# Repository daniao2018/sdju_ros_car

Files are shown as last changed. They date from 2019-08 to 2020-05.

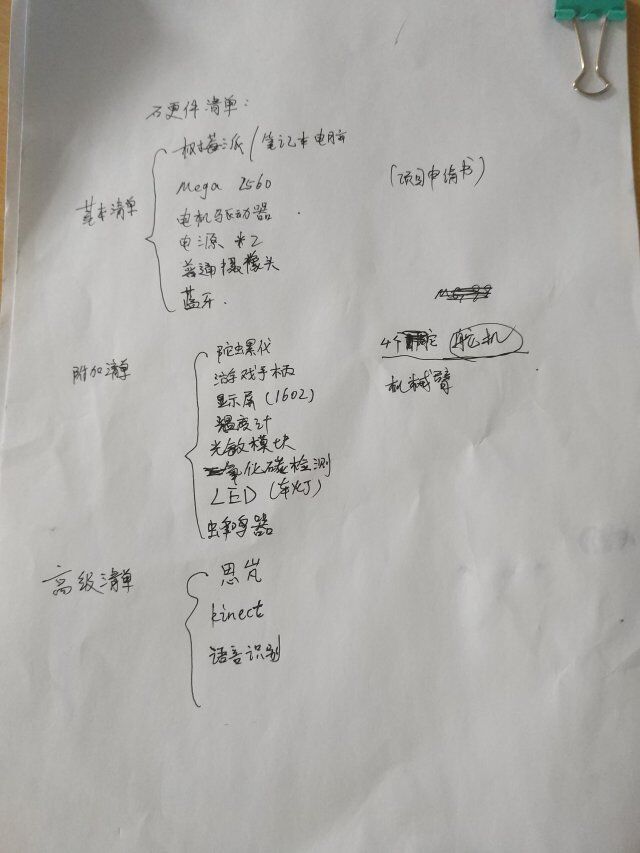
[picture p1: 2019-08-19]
开发文档/项目总体/硬件清单.jpg

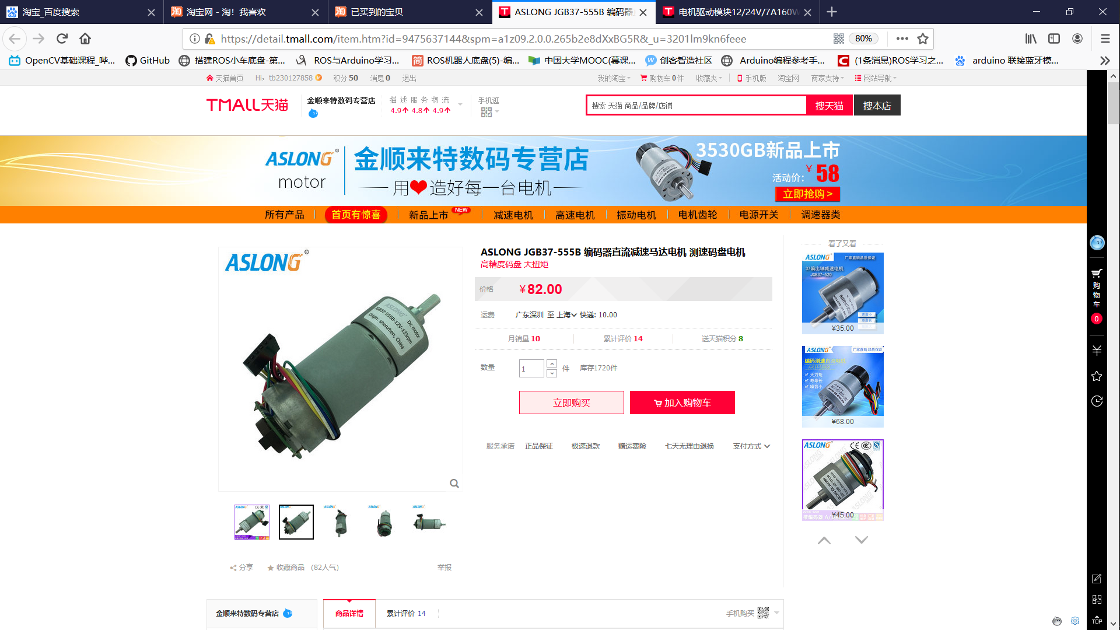
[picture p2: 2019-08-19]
电路部分_F1/电路部分/模块补充图/编码电机.png

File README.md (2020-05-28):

## ROS_Car- 项目介绍

## 项目简介
本项目是博主申请的上海市科创的一部分，题材是基于ROS设计出一款智能配送车，预计经费9000，时间一年。预期成果专利一项。19年3月开题答辩通过，到现在进展了5个月。开展这个项目，是因为博主大一暑假在某家公司实习从事ROS的开发，方向视觉，觉得挺好玩的~~~然后项目申请下来，n多坑，有喜有泪~~~,泪的多。

## 机械结构
项目的机械结构已经完成，小组自主设计了一辆ros小车的机械结构，完成了sw的建模，以及自己加工的过程，太苦了，整个据出来的机械结构。后期可能会请工厂代加工，由于这部分是专利的重点，博主本着保命原则，该部分不开源！！！！
## 电路部分
项目的电路部分已经完成，用fritzing画完了电路图，不会用AD，自己照着仿真图，买现件焊接了小车的电源部分。重点是12v，5v的取电，以及相关按钮的嵌入。在该部分小组还用fritzing画出了项目的连线示意图以及注意事项。
## 代码部 
项目的代码部分，中间层，以及底层都已经完成，可以用opencv，键盘控制小车的运动，后期还有很大的改善空间。主要是一些高级功能模块的迁入。

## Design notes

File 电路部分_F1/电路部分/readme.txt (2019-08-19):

  该部分是小车的电路部分，包括电源模块，小车底盘模块，外置模块以及相关信息的补充。
连线时需考虑代码部分的说明，本部分的某些图的连线方式与代码可能不完全一致，
应以代码部分为主。

配图说明
底盘原理图:
     该部分主要包括电机，电机驱动器，arduino mega 2560 的连线以及取电。：
外置模块电路图：
     该部分主要包括树莓派，arduino mega 2560,蓝牙模块，led,usb摄像头，按钮的取电以及
连接，具体功能模块可以再此模块中拓展。
电源模块：
     该部分主要是通过2块12v的电池给系统提供电力，分别是12v,5v,5v3A稳流，具体分配见图

总体电子元器件（可拓展）
     树莓派
     arduino mega 2560
     电池 12v *2
     直流无刷电机 *2
     电机驱动器
     usb 摄像头
     电源转化器（见附图） *2
     hc-05蓝牙模块
     按钮 *3
     led *n

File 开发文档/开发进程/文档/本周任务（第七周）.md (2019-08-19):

# 本周任务

**电机的调试以及小车模型的建立校正。
项目负责人;高俊，龙宏生。**
## 电机型号：
直流无刷电机，三相五霍尔。100w6A电流（注意安全）2*118元

[电机型号](https://item.taobao.com/item.htm?spm=a230r.1.14.30.3c8f62d0JOuXSm&id=573268079845&ns=1&abbucket=11#detail)
## 电机驱动器：
不提供原理图代码，只提供接线方式，模拟/pwm/电位调速 注意卖家提供的淘宝页信息（后期可更换2*280）       2*46 元

[电机驱动器](https://item.taobao.com/item.htm?spm=a230r.1.14.154.241e3a82ss7VLk&id=534792853206&ns=1&abbucket=11#detail)
## 单片机 stm32控制：
注意stm32的原理图，以及引脚问题。注意差速（pwm）提供转向，不知驱动器里是否有急停，正反转模块？注意系统的学习一下stm32，特别是寄存器的使用，后期的发送数据。 250元
注：不熟悉pwm可来我寝室那块arduino板来pwm调速
[stm32链接](https://s.taobao.com/search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)
## 模型
小车制做完后，可以sw转urdf，在ros中制作好模型。
## 注意事项：
1.	开发流程请注意规范，注意注释的编写
2.	注意培养好阅读博客的好习惯，每一篇博客请精读
3.	注意自己项目笔记的书写
4.	注意项目的进度

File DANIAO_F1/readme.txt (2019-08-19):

/**********总体框架*******************/
/
/test包，小车的中间层，与arduino进行通信，具体见包里面的readme

roslaunch test arduino.launch

//两种控制方式，机理都是发送x,y线速度，z的角速
--------opencv

//先运行usb_cam,启动摄像头

roslaunch usb_cam usb_cam-test.launch

//启动opencv的相关配置

roslaunch opencvfinally 

---------键盘

teleop_twist_keyboard teleop_twist_keyboard.py

调试用的小工具************/

-------检查串口
ls /dev/tty*

------单独编译某个包
catkin_make -DCATKIN_WHITELIST_PACKAGES="test"

-------话题相关
rqt_graph //检查话题之间的关系
rostopic list 
//显示所有话题
rostopic info XXXX //显示单个话题之间订阅以及接收

---------速度相关
rostopic pub /cmd_vel geometry_msgsros/Twist -r 1 -- '[2.0, 0.0, 0.0]' '[0.0, 0.0, 1.8]'

//发布速度
rostopic echo /odom  ？

rosrun rqt_plot rqt_plot
图形化显示？
/odom/pose/pose/orientation

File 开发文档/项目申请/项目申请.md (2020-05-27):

# 项目申请
## 简介

该部分是以前博主为参加项目答辩而攥写的ppt的一部分，主要包括项目人员，研究意义，ros简介，创新点，机械结构，控制方案，现有技术积累等几部部分。现在提取其中的一部分作说明。
## 项目人员

选人组队，好难啊！毕竟是真的要干活的啊，，，当时不懂啊，选了个机制画图，完全正确决定，老哥画图太强了。选了两个本班的，也还可以，毕竟关系亲近。再莫名其妙的塞了两个大一的，带带他们也还说的过去。然后现在好多事情都要我亲自搞，有点累！！！想要考研啊，难受。
## 创新点

当时胡乱写的，答辩的时候被老师怼的不要不要的，主要是机械结构的创新上，你们这个机械结构有什么创新啊？和外面的有什么不同啊？博主当时脑袋一片空白，机械结构不归我管啊，虽然机械结构的加工，组装方式是我提出的，但是当时是为了更好的设计出来这个东西，哪里想过这种事情，毕竟当时草略的sw以经建好了。答辩的结果是博主被老师赶下去了，下一个。难受，难受。
## ROS 简介
略，老师根本没怎么看。
## 控制方案
准备好好讲的时候，被老师赶下去了，太尴尬了。现在想想，控制部分没有什么大的问题，主要是蓝牙模块这方面，是用树莓派内置的，还是外接，或者连到arduino上？？还是很模糊的，而且作为配送车，如何人机互动，用蓝牙开锁没有说清楚，还是有的问题的。
## 总结
该部分是项目的申请部分，当时忙碌了，好久好久，脑段痛，现在想想还是可以的啦。

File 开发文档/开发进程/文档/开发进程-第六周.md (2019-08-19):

# 开发进程-第六周
## 开发规范：
~~请不要讲本项目相关资料外泄~~，谢谢！在Linux平台开发，使用语言，推荐python，也可以用c++。请注意python的缩进格式！编译器使用Linux自带的gredit，可以使用roboware来解决python的缩进问题。写代码时，请注意添加注释，多使用函数类型，少使用全局变量，注意Ros的编程规则，在软件包的外面，请使用空白文档写下，该软件包的运行代码，以及简单注释。
## 技术方案（老版）
该技术方案制定于3月初的样子，后期变化挺大的，在下位机的层次方面，小组使用了arduino mega 2560 代替了stm32。具体原因是某组员居然烧掉了块stm32，小组决定换个容易点的控制方案。总体的时间流程倒是没有什么大的变化。当然这只是大概的技术方案。
技术方案
### 难点：
   请注意专利的撰写时间，请与暑假完成初稿。
   请小车设计的人，设计小车时，考虑他的~~实用新型专利的申请~~（发明）
   请负责控制电机的人学习一下~~stm32的控制方式~~
   请负责整体模块的人保证项目能顺利完成，以及时间进度的控制

### 详细计划：
1.	滋定于每周的星期六晚上开讨论会，如有需要请大家带上笔记本，一起讨论一下本周遇到的问题。
2.	计划借一个实验室用来存放东西，以及学习。
3.	请各模块的负责人把握一下开发进度，遇到问题请及时解决。
项目人员
4.	专利攥写人员，及财务管理：龙宏生，孟纪元
5.	请注意各位培养自己发现问题，解决问题的能力。注意社区，qq群资料的获取。也请各位沉下心来踏实做事。

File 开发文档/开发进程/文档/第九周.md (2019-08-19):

# 第九周
<font color =Coral>测试了arduino对实时ros的通信，主要是通过serial包来进行通讯。</font>
第九周
## 暴露的问题：
1.	arduino的存储能力有限，在执行端不可能写入太多代码，可能也就是数据的写入与pwm调速的功能。
2.	一块arduino板只能写一个节点，完成几个特定的任务？
第九周（二）
3.小车的运动模型还没有建立好，主要是两轮驱动差分底盘的相关问题。即小车转动的角度与两个轮子的数学关系式的问题。
第九周（三）

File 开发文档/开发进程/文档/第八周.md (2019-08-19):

# 本周计划
<font color=red size=3 >以后的讨论，将更多的由各个模块的负责人讨论项目相关进展！注意预期的时间表! </font>
第八周
## Arduino调试中遇到的问题：
1.	电机驱动器的正反转机理没有搞懂。
2.	调试过程中电机没有到达额定功率，24*1.9<100。可能是驱动器（更大）或者电源的保护。
3.	相应的字符串输出没有调试清楚，会出现乱码与报错的问题。
## 具体事宜
1.	请负责底盘控制的人在调完pwm后，注意解决以上问题。
2.	请负责车体的机械结构的人在购买零件时，注意性价比，在上海市那边的钱没有批下来之前，小组只有三百左右的钱支持你的机械结构的设计。
3.	请负责专利撰写的人注意相应知识的学习，也请负责机械结构的人多和他合作一下。
4.	<font color=red size=3 >请各个模块的负责人/组员注意整理项目进展中，遇到的问题，并整理成相应笔记。模块的负责人可以尝试像我这样制作相应模块的本周文档，用来整理项目进展。以后的讨论，更多的是各个模块负责人的讨论以及交流。
 </font>
## 人员的整体框架
人员的整体框架
人员的整体框架（二）
## 项目的预期时间进展表：
•	4月基本了解ROS系统，Linux开发。
•	5月20号之前组装好小车，stm32可以熟练的控制小车的运动。
•	6-7月调试小车的程序，购买其他器件，考虑考试期，希望大家考个好成绩。
•	7-9月，留校调试系统程序，完成一些项目之外的工作，如机器语音，人脸识别，slam自主导航
<font color=red size=3 >•	请负责专利的人在九月之前完成专利申请书的样式，撰写相关专利。 </font>
•	9月，确保小车的功能达到之前的技术积累，并有适当的其他技术积累。
•	10-12月二次开发，添加一些好玩，实际的功能，解决具体实际问题（好参加比赛）。
<font color =red size=3 >•1月以后，预留时间请勿占用。</font>
## 项目开发规范：
<font color =red size=3 >参考以前文档</font>

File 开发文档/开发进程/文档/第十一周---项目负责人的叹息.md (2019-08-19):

# 第十一周---项目负责人的叹息
项目已经开展了一个多月，可以说本学期可以用来完成项目的时间已经不多了，前面的几周一直在讲，相关规范以及如何解决具体问题，也不知道你们听进去了多少，<font color=red size=4>后面的工作应该更多的由相关的项目负责人完成。</font>
**客观的来说，本次项目的开发还是挺有难度的**，主要是任务多（车体的机械结构，底盘的控制，ros编程及相关算法），组员相关知识薄弱（能编程以及会单片机的人少）。<font color=red size=4>有些组员承担了过多的压力，而有些组员则明显的不知道自己要干什么。</font>当然，这也和我的分工以及人员的组配有关。<font color=red size=4>很明显，有些任务太难了，需要的时间有点长，这个时候需要waiting & help。</font>有些组员由于个人原因以及其他原因是得寻找一些适合他的活干，这也是一个大问题。
作为项目负责人，如何分配任务，以及考虑人员的能力还是有点挑战性的，你不可能每一件事情，都亲自去做。也不可能将一些明显不适合组员的任务分配下去。
**总的来说，是希望每一个组员通过这个项目学到点什么，有自己的一技之长的。当然，站在组长的角度上来看，我首先得保证项目得顺利完成以及相应功能的实现。站在个人的角度来看，你是不希望由于这个项目而破坏同学之间的友谊的。**

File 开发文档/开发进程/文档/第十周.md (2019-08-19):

# 项目陷入了瓶颈期
### 具体体现在如下方面：
**1.	大概有300块钱的东西被烧了（一个stm32和一个驱动板）
2.	控制思路不清晰，小车定位有点问题。**
### 控制思路：
第十周

<font color=red size =5>大意如下：</font>
第十周（二）
### 小车定位：
**以完成申请书上的东西为主，可以负重一点点，但重点不是落在负重上。而是小车的机械结构与控制上。**
第十周（三）
## 一些问题：
<font color=red size=3>a.电机的选型出了问题，100w/2500转，导致转矩为0.4n*m，不能承重？解决方法？</font>
1.增加减速机构，以增大转矩。
2.换电机，底层机械设计重新改进
  个人偏向第二种解决方法：第一种方案可以保留，如果有人想继续做下去的话，思路是增加减速结构，选一个好一点的驱动器（2个500以上？），能读出转速发送给单片机的那种，然后整合到小车上。
<font color=red size=3>b.时间，时间，时间，这个项目很有挑战性，花的时间有点多，需要克服一下。而且马上就期末了，我不可能揽下所有事情，所以会有分工。</font>
c.	干活毅力很重要，现在出现的一些问题都是小问题，不要乱了阵脚。
#### d.	小车的一些性能指标:
1.	最大线速度1m/s 
2.	转矩6n*m以上，可能还要计算一下
3.	预期称重30kg

**e	购买东西：预算3000左右，等上海市那边的钱批下来，先看。**
电池：500  	
树莓派：300-400 // 32g内存，3b（3b+）
直流无刷减速电机*2    300  //AB相编码器
Stm32：200
机械结构 500 
Arduino：200-250 //uno mege2560
Kinetic  300（不知道有发票吗）
Imu 200
语言识别模块 200
硬盘*2  100

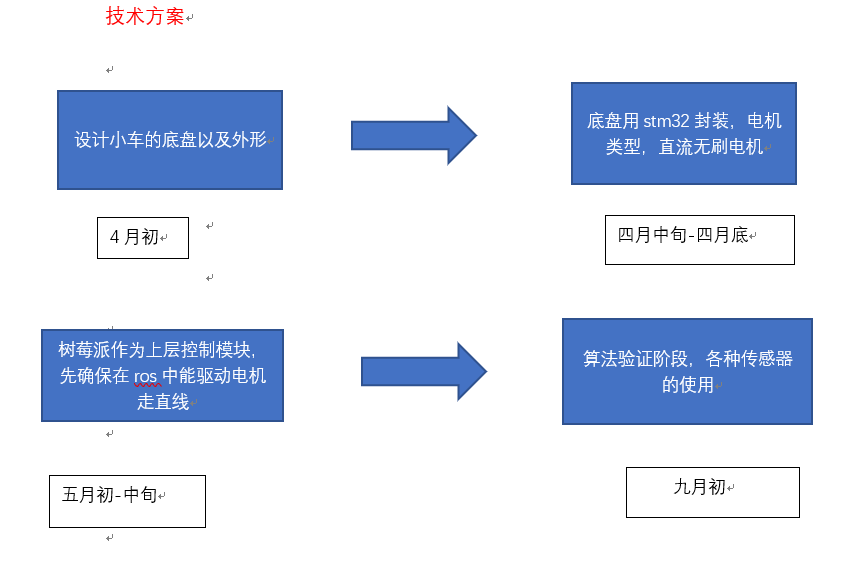
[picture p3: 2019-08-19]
开发文档/开发进程/图片/技术方案.png

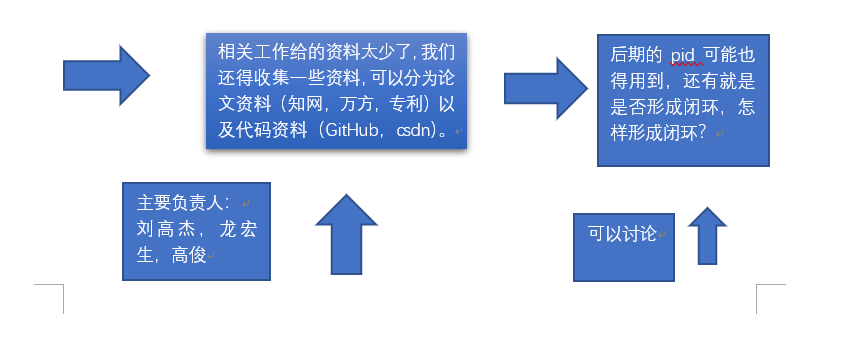
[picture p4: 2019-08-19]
开发文档/开发进程/图片/第九周（三）.png

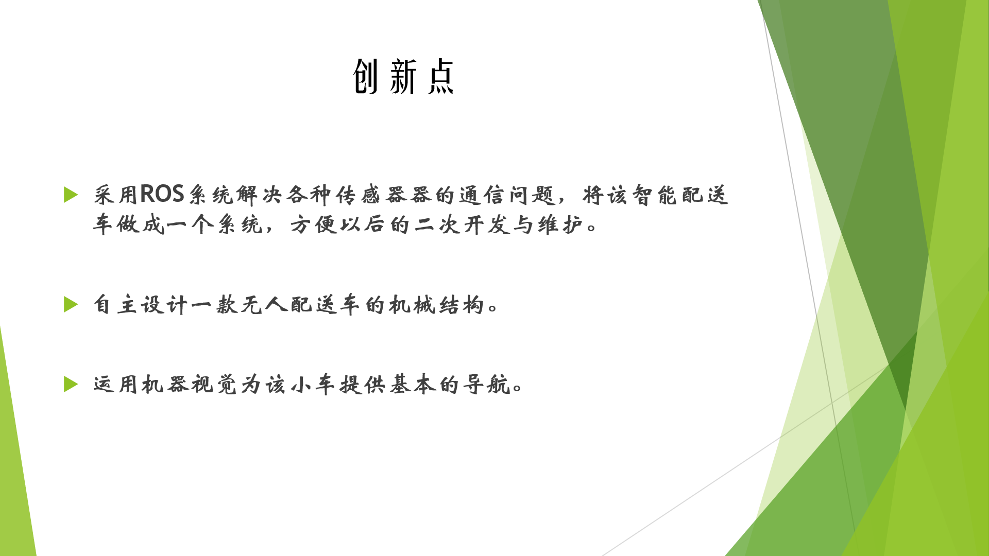
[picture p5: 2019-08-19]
开发文档/项目申请/创新点.png

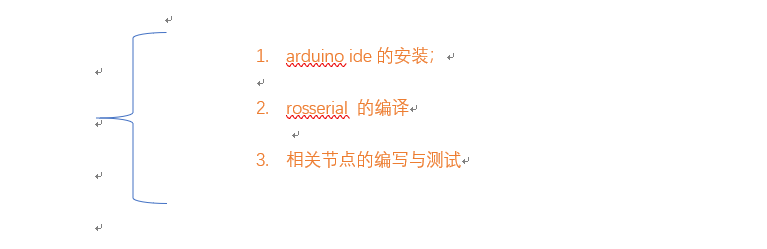
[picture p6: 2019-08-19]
开发文档/开发进程/图片/第九周.png

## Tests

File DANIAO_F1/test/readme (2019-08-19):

//显示消息
rosmsg show beginner_tutorials/Num
rosmsg show beginner_tutorials/SensorState
//显示服务
rossrv show beginner_tutorials/ServoWrite.srv
//单独一个包编译
catkin_make -DCATKIN_WHITELIST_PACKAGES="test"
//登录
roscore
roslaunch test arduino.launch
rostopic pub /cmd_vel geometry_msgs/Twist -r 1 -- '[2.0, 0.0, 0.0]' '[0.0, 0.0, 1.8]'
//注意senor。py还没有调试好，在arduino。node里面注释掉了两行

rosrun teleop_twist_keyboard teleop_twist_keyboard.py

//登录
roscore
roslaunch test arduino.launch
rosrun teleop_twist_keyboard teleop_twist_keyboard.py
//检查串口
ls /dev/tty*
//显示
rostopic pub /cmd_vel geometry_msgsros/Twist -r 1 -- '[2.0, 0.0, 0.0]' '[0.0, 0.0, 1.8]'
rostopic echo /odom 
rosrun rqt_plot rqt_plot
/odom/pose/pose/orientation
//话题之间的关系
rqt_graph

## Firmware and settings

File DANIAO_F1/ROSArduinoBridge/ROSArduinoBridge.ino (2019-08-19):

//这是在官方包基础上修改来的
#include <string.h>

#define USE_BASE      // Enable the base controller code 是否使用base controller
//#undef USE_BASE     // Disable the base controller code

/* Define the motor controller and encoder library you are using */
//定义电机控制方式，使用ifdef 的方式，和正常的if 语句类似
#ifdef USE_BASE
/* The Pololu VNH5019 dual motor driver shield */
//#define POLOLU_VNH5019

/* The Pololu MC33926 dual motor driver shield */
//#define POLOLU_MC33926

/* The RoboGaia encoder shield */
//#define ROBOGAIA

/* Encoders directly attached to Arduino board */
//#define ARDUINO_ENC_COUNTER

#define FUCKING_GARBAGE_MOTOR_DRIVER

/* L298 Motor driver*/
//#define L298_MOTOR_DRIVER　//这里只是借用名称，之后需要自己更改驱动
#endif

//#define USE_SERVOS  // Enable use of PWM servos as defined in servos.h
#undef USE_SERVOS     // Disable use of PWM servos //不适用SERVOS

/* Serial port baud rate */
#define BAUDRATE     57600 //波特率

/* Maximum PWM signal */
#define MAX_PWM        255 //最大pwm
#define MAX_INPUT        255 //最大速度限制，防止倒转


#if defined(ARDUINO) && ARDUINO >= 100 //不知到用处
#include "Arduino.h"
#else
#include "WProgram.h"
#endif

/* Include definition of serial commands */
#include "commands.h"

/* Sensor functions */
//#include "sensors.h"　//不使用

/* Include servo support if required */
#ifdef USE_SERVOS
#include <Servo.h>
#include "servos.h"
#endif

#ifdef USE_BASE
/* Motor driver function definitions */
#include "motor_driver.h"//加载电机控制头文件

/* Encoder driver function definitions */
#include "encoder_driver.h"//加载编码器控制头文件

/* PID parameters and functions */
#include "diff_controller.h"//加载PID控制

/* Run the PID loop at 30 times per second */
#define PID_RATE 30     // Hz　pid控制频率

/* Convert the rate into an interval */
const int PID_INTERVAL = 1000 / PID_RATE;


/* Track the next time we make a PID calculation */
unsigned long nextPID = PID_INTERVAL;

/* Stop the robot if it hasn't received a movement command
  in this number of milliseconds */
#define AUTO_STOP_INTERVAL 2000  // 用来控制每次串口命令的作用时间（对电机），每次电机运行这个时间后停止，等待下次命令
long lastMotorCommand = AUTO_STOP_INTERVAL;
#endif

/* Variable initialization */

// A pair of varibles to help parse serial commands (thanks Fergs)
int arg = 0;
int index = 0;

// Variable to hold an input character
char chr;

// Variable to hold the current single-character command
char cmd;

// Character arrays to hold the first and second arguments
char argv1[16];
char argv2[16];

// The arguments converted to integers
long arg1;
long arg2;

/* C下面出现警告，原文为： cmd = NULL; */
void resetCommand() {
  cmd = 0;
  memset(argv1, 0, sizeof(argv1));
  memset(argv2, 0, sizeof(argv2));
  arg1 = 0;
  arg2 = 0;
  arg = 0;
  index = 0;
}

//运行命令，命令在commands.h中被定义
int runCommand() {
  int i = 0;
  char *p = argv1;
  char *str;
  int pid_args[4]; //由于左右电机使用不同的pid参数，一面要4个
  arg1 = atoi(argv1);
  arg2 = atoi(argv2);

  switch (cmd) {
    case READ_PIDIN: //与commands.h中的匹配 这里为添加的，原代码中没有
      Serial.print( readPidIn(LEFT));
      Serial.print(" ");
      Serial.println( readPidIn(RIGHT));
      break;
    case READ_PIDOUT://为了方便之后的PID调整
      Serial.print( readPidOut(LEFT));
      Serial.print(" ");
      Serial.println( readPidOut(RIGHT));
      break;
    case GET_BAUDRATE:
      Serial.println(BAUDRATE);
      break;
    case ANALOG_READ:
      Serial.println(analogRead(arg1));
      break;
    case DIGITAL_READ:
      Serial.println(digitalRead(arg1));
      break;
    case ANALOG_WRITE:
      analogWrite(arg1, arg2);
      Serial.println("OK");
      break;
    case DIGITAL_WRITE:
      if (arg2 == 0) digitalWrite(arg1, LOW);
      else if (arg2 == 1) digitalWrite(arg1, HIGH);
      Serial.println("OK");
      break;
    case PIN_MODE:
      if (arg2 == 0) pinMode(arg1, INPUT);
      else if (arg2 == 1) pinMode(arg1, OUTPUT);
      Serial.println("OK");
      break;
      /*case PING:
        Serial.println(Ping(arg1));
        break;*/
#ifdef USE_SERVOS
    case SERVO_WRITE:
      servos[arg1].setTargetPosition(arg2);
      Serial.println("OK");
      break;
    case SERVO_READ:
      Serial.println(servos[arg1].getServo().read());
      break;
#endif

#ifdef USE_BASE
    case READ_ENCODERS:
      Serial.print(readEncoder(LEFT));
      Serial.print(" ");
      Serial.println(readEncoder(RIGHT));
      break;
    case RESET_ENCODERS:
      resetEncoders();
      resetPID();   // 初始化pid
      Serial.println("RESET_ENCODERS OK");
      break;
    case MOTOR_SPEEDS:
      /* Reset the auto stop timer */
      lastMotorCommand = millis();
      if (arg1 == 0 && arg2 == 0) {
        setMotorSpeeds(0, 0);
        resetPID();
        moving = 0;
      }
      else moving = 1;
      leftPID.TargetTicksPerFrame = arg1;   //从串口读到的电机速度赋值给这个变量，并传递到doPID中
      rightPID.TargetTicksPerFrame = arg2;
      Serial.println("OK");
      //     setMotorSpeeds(arg1, arg2);
      //  test   test    test   test   test   test   test   test   test   test  //




      //  test   test    test   test   test   test   test   test   test   test  //
      break;
    case UPDATE_PID:
      while ((str = strtok_r(p, ":", &p)) != '\0') {
        pid_args[i] = atoi(str);
        i++;
      }
      lKp = pid_args[0];
      lKd = pid_args[1];
      lKi = pid_args[2];
      lKo = pid_args[3];

      rKp = pid_args[0];
      rKd = pid_args[1];
      rKi = pid_args[2];
      rKo = pid_args[3];

      Serial.println("OK");
      break;
#endif
    default:
      Serial.println("Invalid Command");
      break;
  }
}

/* Setup function--runs once at startup. */
//记得初始化那些函数
void setup() {
  Serial.begin(BAUDRATE);

  // Initialize the motor controller if used */
#ifdef USE_BASE
#ifdef ARDUINO_ENC_COUNTER
  //set as inputs
  DDRD &= ~(1 << LEFT_ENC_PIN_A);
  DDRD &= ~(1 << LEFT_ENC_PIN_B);
  DDRC &= ~(1 << RIGHT_ENC_PIN_A);
  DDRC &= ~(1 << RIGHT_ENC_PIN_B);

  //enable pull up resistors
  PORTD |= (1 << LEFT_ENC_PIN_A);
  PORTD |= (1 << LEFT_ENC_PIN_B);
  PORTC |= (1 << RIGHT_ENC_PIN_A);
  PORTC |= (1 << RIGHT_ENC_PIN_B);

  // tell pin change mask to listen to left encoder pins
  PCMSK2 |= (1 << LEFT_ENC_PIN_A) | (1 << LEFT_ENC_PIN_B);
  // tell pin change mask to listen to right encoder pins
  PCMSK1 |= (1 << RIGHT_ENC_PIN_A) | (1 << RIGHT_ENC_PIN_B);

  // enable PCINT1 and PCINT2 interrupt in the general interrupt mask
  PCICR |= (1 << PCIE1) | (1 << PCIE2);
#endif
  initEncoders();
  initMotorController();
  resetPID();
#endif

  /* Attach servos if used */
#ifdef USE_SERVOS
  int i;
  for (i = 0; i < N_SERVOS; i++) {
    servos[i].initServo(
      servoPins[i],
      stepDelay[i],
      servoInitPosition[i]);
  }
#endif
}

/* Enter the main loop.  Read and parse input from the serial port
   and run any valid commands. Run a PID calculation at the target
   interval and check for auto-stop conditions.
*/
void loop() {
  while (Serial.available() > 0) {

    // Read the next character
    chr = Serial.read();

    // Terminate a command with a CR
    if (chr == 13) {
      if (arg == 1) argv1[index] = NULL;
      else if (arg == 2) argv2[index] = NULL;
      runCommand();
      resetCommand();
    }
    // Use spaces to delimit parts of the command
    else if (chr == ' ') {
      // Step through the arguments
      if (arg == 0) arg = 1;
      else if (arg == 1)  {
        argv1[index] = NULL;
        arg = 2;
        index = 0;
      }
      continue;
    }
    else {
      if (arg == 0) {
        // The first arg is the single-letter command
        cmd = chr;
      }
      else if (arg == 1) {
        // Subsequent arguments can be more than one character
        argv1[index] = chr;
        index++;
      }
      else if (arg == 2) {
        argv2[index] = chr;
        index++;
      }
    }
  }

  // If we are using base control, run a PID calculation at the appropriate intervals
#ifdef USE_BASE
  if (millis() > nextPID) {
    updatePID();
    nextPID += PID_INTERVAL;
  }

  // Check to see if we have exceeded the auto-stop interval
  if ((millis() - lastMotorCommand) > AUTO_STOP_INTERVAL) {
    ;
    setMotorSpeeds(0, 0);   // 用来控制每次串口命令的作用时间（对电机），每次电机运行这个时间后停止，等待下次命令
    moving = 0;
  }
#endif

  // Sweep servos
#ifdef USE_SERVOS
  int i;
  for (i = 0; i < N_SERVOS; i++) {
    servos[i].doSweep();
  }
#endif
}

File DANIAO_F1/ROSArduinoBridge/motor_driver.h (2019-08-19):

/***************************************************************
   Motor driver function definitions - by James Nugen
   *************************************************************/
//

 
#ifdef FUCKING_GARBAGE_MOTOR_DRIVER 

  #define RIGHT_MOTOR_PWM 10
  #define RIGHT_MOTOR_IN2 9 
  #define RIGHT_MOTOR_IN1 8
  
  #define LEFT_MOTOR_PWM 7
  #define LEFT_MOTOR_IN2 5
  #define LEFT_MOTOR_IN1 6

  
#elif L298_MOTOR_DRIVER

  #define RIGHT_MOTOR_BACKWARD 8
  #define LEFT_MOTOR_BACKWARD  5
  #define RIGHT_MOTOR_FORWARD  9
  #define LEFT_MOTOR_FORWARD   6

  
#endif
void initMotorController();
void setMotorSpeed(int i, int spd);
void setMotorSpeeds(int leftSpeed, int rightSpeed);
boolean direction(int i);

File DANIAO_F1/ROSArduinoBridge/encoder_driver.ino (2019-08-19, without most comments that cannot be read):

//* *************************************************************//
  // Encoder definitions
  // Add an "#ifdef" block to this file to include support for
 //  a particular encoder board or library. Then add the appropriate
 //  #define near the top of the main ROSArduinoBridge.ino file.
  // ************************************************************ */
 
#ifdef USE_BASE
 
 
#include "motor_driver.h"
#include "commands.h"
/* Wrap the encoder reset function */
 
volatile long left_enc_pos = 0L;
volatile long right_enc_pos = 0L;
 

 
int left_rotate = 0;
int right_rotate = 0;
 
 

void initEncoders() {
  pinMode(2, INPUT);
  pinMode(3, INPUT);
  pinMode(19, INPUT);
  pinMode(18, INPUT);
  attachInterrupt(0, encoderLeftISR, CHANGE);
  attachInterrupt(1, encoderLeftISR,  CHANGE);
  attachInterrupt(4, encoderRightISR, CHANGE);
  attachInterrupt(5, encoderRightISR, CHANGE);
}
 

void encoderLeftISR() {
  if (direction(LEFT) == BACKWARDS) {
 
    left_enc_pos--;
  }
 
  else {
    left_enc_pos++;
  }
}
 
void encoderRightISR() {
  if (direction(RIGHT) == BACKWARDS) {
    right_enc_pos--;
  } else {
    right_enc_pos++;
  }
}
 
long readEncoder(int i) {
  long encVal = 0L;
  if (i == LEFT)  {
    noInterrupts();
    encVal = left_enc_pos;
    interrupts();
  }
  else {
    noInterrupts();
    encVal = right_enc_pos;
    interrupts();
  }
  return encVal;
}
 
/* Wrap the encoder reset function */

void resetEncoder(int i) {
  if (i == LEFT) {
    left_enc_pos = 0L;
    return;
  } else {
    right_enc_pos = 0L;
    return;
  }
}
 
/* Wrap the encoder reset function */

void resetEncoders() {
  resetEncoder(LEFT);
  resetEncoder(RIGHT);
}
 
#endif

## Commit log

2019-08-19 添加开发文档
2019-08-19 电路部分
    截至至2019.08.01，后期可能需要改进
    [外置模块电路图.fzz, 底盘原理图.fzz, 电源模块.fzz]
2019-08-19 代码部分_F1
    初步代码，截至到2019.07.20
